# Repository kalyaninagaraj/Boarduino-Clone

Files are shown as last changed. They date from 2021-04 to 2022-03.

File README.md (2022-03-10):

# Boarduino Clone 
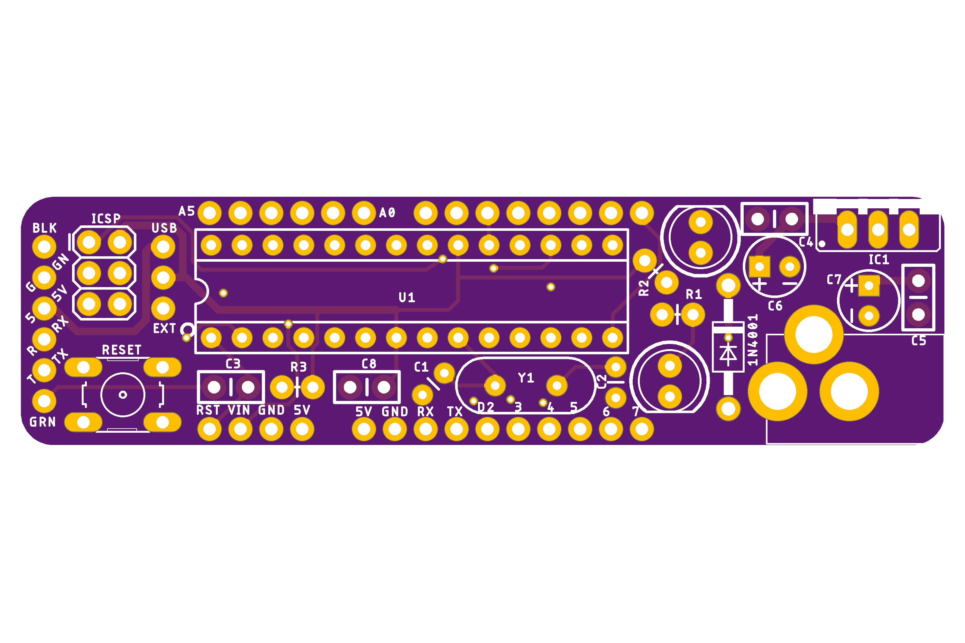
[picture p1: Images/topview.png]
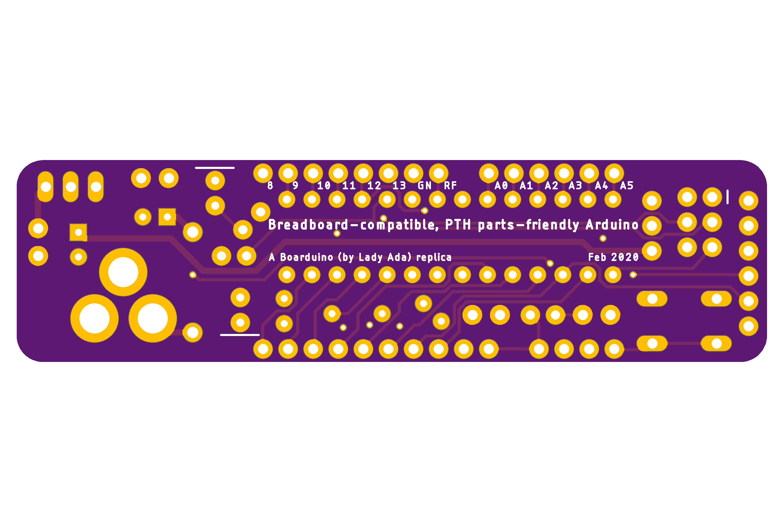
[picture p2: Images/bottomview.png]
&nbsp;&nbsp; <br />
This clone-of-a-clone is an adaptation of the breadboard and through-hole parts-friendly [Arduino Uno](https://store.arduino.cc/usa/arduino-uno-rev3), a.k.a. [Boarduino by Lady Ada](https://learn.adafruit.com/boarduino-kits). 

The orginal Boarduino was designed with a ceramic resonator in mind, which isn't available at my local electronics stores. So I redesigned the layout in [Autodesk EAGLE](https://www.autodesk.com/products/eagle) to make space for the more readily available crystal oscillator. 

## Final Product
Check out this [blinking LED demo](https://youtu.be/2WAObtuopfo) for a look at the final (manufactured and assembled) board. 

### A Note On The Microcontroller 
I could only manage to get my hands on a [ATMEGA328-PU](https://www.microchip.com/wwwproducts/en/ATMEGA328), and not the Arduino-supported [ATMEGA328P-PU](https://www.microchip.com/wwwproducts/en/ATMEGA328P), which means bootloading troubles! Of the handful of workarounds that I found on the web, [this one](http://www.crash-bang.com/resource/bootload-atmega328/) helped the most.  

## Resources
Here are links to the original Boarduino, other Boarduino-like products, and some related resources. 
1. [DC and USB Boarduino kits and assembly tutorial by Lada Ada, Adafruit Industries](https://learn.adafruit.com/boarduino-kits). 
2. [Really Bare Bones Board (RBBB) by Modern Device](https://moderndevice.com/product/rbbb-kit/). Their [document on assembly instructions](https://cdn.shopify.com/s/files/1/0038/9582/files/RBBB_Instructions_06.pdf?1260749296) includes a great how-to section for soldering novices.
3. If the purple PCB in the video wasn't enough of a hint, I got the boards fabricated from [OSH Park](https://oshpark.com/)! 

## Design Credit
[@kalyaninagaraj](https://github.com/kalyaninagaraj)

## Hardware License
The design files are made available under [CC BY-SA 3.0](https://creativecommons.org/licenses/by-sa/3.0/).

## Tags
#Open-Source Hardware #Arduino Uno Clone # Boarduino Clone #Adafruit

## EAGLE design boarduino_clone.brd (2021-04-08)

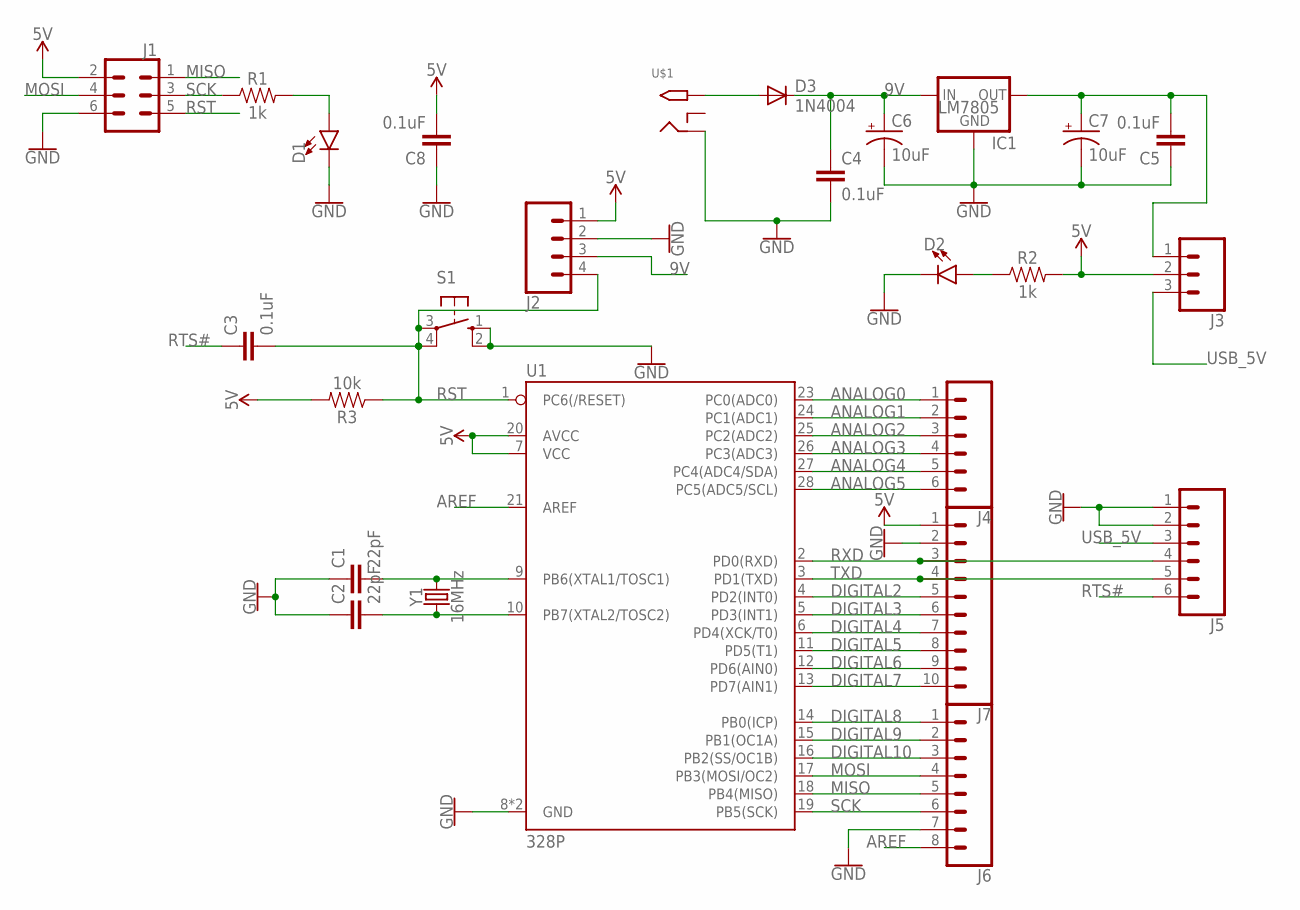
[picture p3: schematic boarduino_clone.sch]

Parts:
C1, C2: 22pF; CAP-PTH-2.54
C3, C4, C5, C8: 0.1uF; CAP-PTH-SMALL-KIT
C6, C7: 10uF; CPOL-RADIAL-2.5MM-5MM
D1, D2: LED5MM; LED_5MM
D3: 1N4004; DO41-10
IC1: LM7805; 78XXS
J1: FEMALE 2x3; 2X3
J2: CONN_041X04_NO_SILK; 1X04_NO_SILK
J3: CONN_031X03_NO_SILK; 1X03_NO_SILK
J4, J5: CONN_06NO_SILK_FEMALE_PTH; 1X06_NO_SILK
J6: CONN_08NO_SILK_FEMALE_PTH; 1X08_NO_SILK
J7: CONN_10NO_SILK_PTH_FEMALE; 1X10_NO_SILK
R1, R2: 1k; AXIAL-0.1
R3: 10k; AXIAL-0.1
S1: 10-XX; B3F-10XX
U1: 328P; DIP28
U$1: 2.1MMJACKTHM; PJ-102A
Y1: 16MHz; HC49US

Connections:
5V: C8.2, J1.2, J2.1, J3.2, J7.1, R2.P$2 (2), R3.P$2 (2), U1.7 (VCC), U1.20 (AVCC)
9V: C4.1, C6.1 (+), D3.C, IC1.IN, J2.3
ANALOG0: J4.1, U1.23 (PC0(ADC0))
ANALOG1: J4.2, U1.24 (PC1(ADC1))
ANALOG2: J4.3, U1.25 (PC2(ADC2))
ANALOG3: J4.4, U1.26 (PC3(ADC3))
ANALOG4: J4.5, U1.27 (PC4(ADC4/SDA))
ANALOG5: J4.6, U1.28 (PC5(ADC5/SCL))
AREF: J6.8, U1.21 (AREF)
DIGITAL2: J7.5, U1.4 (PD2(INT0))
DIGITAL3: J7.6, U1.5 (PD3(INT1))
DIGITAL4: J7.7, U1.6 (PD4(XCK/T0))
DIGITAL5: J7.8, U1.11 (PD5(T1))
DIGITAL6: J7.9, U1.12 (PD6(AIN0))
DIGITAL7: J7.10, U1.13 (PD7(AIN1))
DIGITAL8: J6.1, U1.14 (PB0(ICP))
DIGITAL9: J6.2, U1.15 (PB1(OC1A))
DIGITAL10: J6.3, U1.16 (PB2(SS/OC1B))
GND: C1.1, C2.1, C4.2, C5.1, C6.2 (-), C7.2 (-), C8.1, D1.K (C), D2.K (C), IC1.GND, J1.6, J2.2, J5.1, J5.2, J6.7, J7.2, S1.1 (S), S1.2 (S1), U1.8 (GND), U1.22 (GND), U$1.RING
MISO: J1.1, J6.5, U1.18 (PB4(MISO))
MOSI: J1.4, J6.4, U1.17 (PB3(MOSI/OC2))
unnamed: D1.A, R1.P$2 (2)
unnamed: C1.2, U1.9 (PB6(XTAL1/TOSC1)), Y1.2
unnamed: C2.2, U1.10 (PB7(XTAL2/TOSC2)), Y1.1
unnamed: D3.A, U$1.TIP
unnamed: C5.2, C7.1 (+), IC1.OUT, J3.1
unnamed: D2.A, R2.P$1 (1)
RST: C3.2, J1.5, J2.4, R3.P$1 (1), S1.3, S1.4 (P1), U1.1 (PC6(/RESET))
RTS#: C3.1, J5.6
RXD: J5.4, J7.3, U1.2 (PD0(RXD))
SCK: J1.3, J6.6, R1.P$1 (1), U1.19 (PB5(SCK))
TXD: J5.5, J7.4, U1.3 (PD1(TXD))
USB_5V: J3.3, J5.3

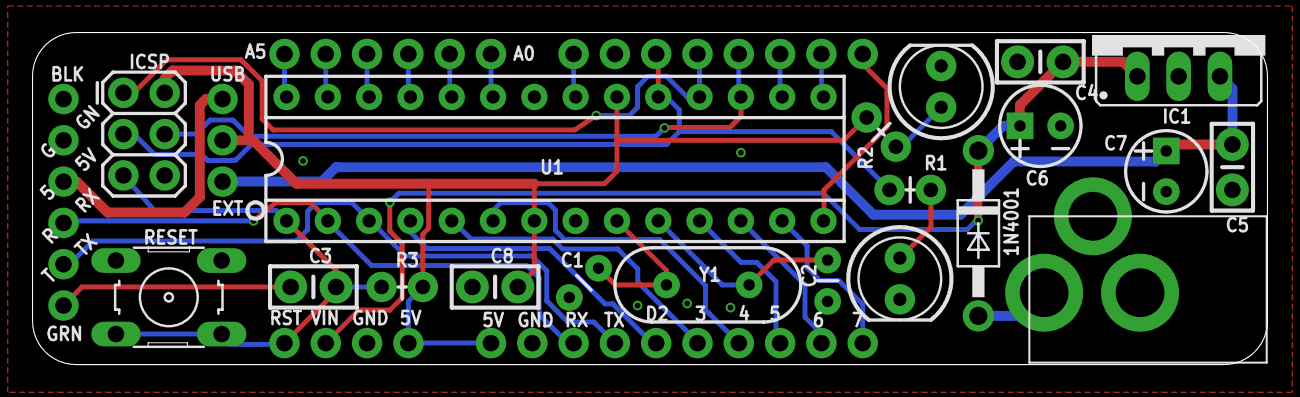
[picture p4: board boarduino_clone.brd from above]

Board: 2 copper layers, 75.9 x 20.4 mm, 26 parts (0 on the bottom side), 33 nets.

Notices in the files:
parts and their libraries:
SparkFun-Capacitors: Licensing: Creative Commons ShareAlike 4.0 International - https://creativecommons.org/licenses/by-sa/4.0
